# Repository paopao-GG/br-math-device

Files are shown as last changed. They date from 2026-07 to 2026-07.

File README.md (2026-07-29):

# BR Math Device

Arduino Mega firmware for a 3-level multiple-choice quiz prop. Questions are on
paper; the device judges the answers. See [TDD.md](TDD.md) for the full design.

## How it plays

Three levels hold nine questions between them. One LED and one button belong to each
**level**, not to each question:

| Level | Questions | Code digits it locks | Button | LED |
|---|---|---|---|---|
| 1 | 5 | 1, 2, 3 | 23 | 22 |
| 2 | 3 | 4 | 25 | 24 |
| 3 | 1 | 5 | 27 | 26 |

**Pick a set first.** There are three sets of paper questions, each with its own four
RFID cards (twelve in all). At boot the LCD shows `SCAN TO PICK SET`; the player scans
any card from the set they want, then presses **button 1** to confirm:

```
SCAN TO PICK SET          SET 2 SELECTED
ANY A/B/C/D CARD   -->     PRESS 1 TO START   -->  game begins on set 2
```

Scanning a different set's card changes the choice; an unrecognised card is ignored.
To change sets after starting, power-cycle.

Once a set is confirmed the device picks a random 5-digit code (digits 1–9, different
every boot) and shows it on the LCD. Each level then runs in two phases:

**Quiz phase** — scan one of the selected set's four RFID cards (A/B/C/D) as the
answer, press the level's button.

```
CODE:47391 L1Q3     <- the code, then level 1 question 3
ANS:C   [##...]     <- the scanned card, then this level's 5 questions
```

- correct → the LED **blinks twice** and the next question opens
- wrong, or no card scanned → **no blink**, miss tune, and the *same question stays
  live*. There is no way past a question except by answering it.

**Code phase** — once every question in the level is cleared, dial the level's share
of the code on the potentiometer and press the same button to lock each digit.

```
CODE:47391 L1D2     <- level 1, code digit 2 of the 3 it owns
DIAL:7  [47_..]     <- the live pot digit, then all five code slots
```

- correct digit → LED blinks once, digit latches, next slot opens
- wrong digit → no blink, miss tune, retry the same slot
- the level's **last** digit → LED goes **solid** and the next level begins

After level 3's digit locks, all three LEDs are solid and the LCD shows `SOLVED!`
with the code and a `MISSES:n` count. Because a question can only be retried, every
game ends solved — the miss count is what says how cleanly. Power-cycle for a new code.

Each set has its own fixed answer key (`ANSWER_KEYS` in [config.h](config.h)), laid out
`L1 (5) | L2 (3) | L3 (1)`:

| Set | L1 Q1–5 | L2 Q1–3 | L3 |
|---|---|---|---|
| **1** | B D A C D | A C B | D |
| **2** | C A D B A | D B C | A |
| **3** | D B C A B | C A D | B |

Only the selected set's cards score; a card from another set reads as `?` and counts
wrong.

## Wiring (Arduino Mega 2560)

Summary below. **[WIRING.md](WIRING.md) has the wire-by-wire tables** — use that one at
the bench.

| Part | Pins |
|---|---|
| RC522 RFID | SS→53, SCK→52, MOSI→51, MISO→50, RST→49, **VCC→3.3V**, GND→GND |
| 1602 I2C LCD | SDA→20, SCL→21, VCC→5V, GND→GND |
| Potentiometer ×1 | wiper → A0; outer legs → 5V and GND |
| LEDs ×3 | 22, 24, 26 → 220Ω resistor → LED → GND |
| Buttons ×3 | 23, 25, 27 → button → GND (no resistors; internal pullups) |
| Passive buzzer | 8 → buzzer → GND |
| A15 | **leave unconnected** |

Two things bite people here:

- **The RC522 runs on 3.3V.** Putting it on 5V destroys it. Its logic pins are fine
  on the Mega's 5V SPI lines; it's only VCC that matters.
- **A15 must stay floating.** Its electrical noise is what seeds the random code.
  Wire anything to it and every boot produces the same code.

LED 1 goes with button 1 and level 1, and so on. The single potentiometer is shared by
every level.

LEDs on 28/30 and buttons on 29/31 are left over from the earlier five-round build. They
stay wired and are never read or driven — the firmware doesn't even configure those pins.

## Libraries

Two are needed, both via the Arduino IDE's **Library Manager**:

- **MFRC522** (by GithubCommunity) — for the RFID reader. Not yet installed.
- **LiquidCrystal I2C** — already installed here (Frank de Brabander's version).

Several different libraries are all called "LiquidCrystal_I2C" and they disagree on
how to start the display — de Brabander's uses `begin()`, the others use `init()`.
The sketch detects which one you have at compile time and calls the right one, so any
of them will work. You don't need to do anything about this; it's noted only because
the resulting error message (`no member named 'begin'`) is otherwise baffling.

## Bring-up

**1. The card UIDs are already filled in.** All twelve (three sets × A/B/C/D) are in
`CARD_UIDS` in [config.h](config.h), transcribed from `rfid-uid.txt`. You only need the
next two steps if you **replace a card** or add a new one.

**2. (Only if replacing a card) Read its UID.** Open `tools/uid_dump/uid_dump.ino` in
the Arduino IDE, upload it, open the Serial Monitor at 9600 baud, and tap the card. It
prints a paste-ready line:

```
Card detected!
  UID (hex):  DE AD BE EF
  Paste this: {0xDE, 0xAD, 0xBE, 0xEF},
```

Paste it into the right `CARD_UIDS[set][letter]` slot. The order matters on both axes —
outer index is the set (0=set 1…), inner is A, B, C, D — because `ANSWER_KEYS` indexes
into it, so a wrong slot scores that set against the wrong card. If a card prints nothing
at all, the reader is miswired or on 5V.

**3. Flash the game.** Open `br-math-device.ino` in the Arduino IDE and upload.

(If you prefer the command line, PlatformIO works too: `pio run -t upload` for the
game, `pio run -d tools/uid_dump -t upload` for the UID reader.)

## Checks

- Blank or garbled LCD: run an I2C scanner and change `LCD_ADDR` in config.h to `0x3F`.
- Scan beep too quiet to hear across the room: raise the duration in `TUNE_SCAN`
  (config.h). It beeps on every recognised card read.
- Set selection sanity check: at boot, scan one card from each set — each should report
  its own set (`SET 1/2/3`). If two different cards report the same set, or the wrong
  one, the `CARD_UIDS` blocks in config.h are ordered wrong.
- Digit flickering between two values as the pot rests: raise `POT_HYSTERESIS`. Pot
  feeling sticky or refusing to reach 1 or 9: lower it.
- Turning the pot must only ever change the digit in the `_` slot. If it also moves a
  digit you already locked in, the latch is broken.
- The pot is deliberately dead during a quiz phase — `DIAL:` only appears once all of a
  level's questions are answered. That's not a fault.
- The one test worth doing deliberately: answer a question with the **wrong card**. The
  LED must not blink and the LCD must still show the same `LxQy`. That proves the
  retry rule is live — a question can't be skipped, only answered.
- The Serial Monitor narrates the whole game — the code, each question's expected card,
  each slot's expected digit, what was scanned or dialed, and every miss.

## Layout

- `br-math-device.ino` — the game
- `config.h` — pins, per-set answer keys, card UIDs, tunes, tuning constants. Everything
  you'd want to change is in here.
- `WIRING.md` — wire-by-wire connection tables
- `TDD.md` — the design doc: hardware, game flow, rules
- `tools/uid_dump/` — the card UID reader
- `platformio.ini` — for building from the CLI; the Arduino IDE works without it

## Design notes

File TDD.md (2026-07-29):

# TDD — Math Device

Technical design for a 3-level multiple-choice quiz device built on an Arduino Mega.
The questions are printed on paper; the device's job is to take the player's answer
physically — as an RFID card, and later as a dialed digit — and judge it.

## Hardware Components

| Qty | Component |
|-----|---|
| 1 | Arduino Mega |
| 1 | RFID reader (RC522) |
| 12 | RFID card — 3 sets of 4, each marked A, B, C, D |
| 3 | Push button |
| 3 | LED |
| 1 | Potentiometer |
| 1 | 1602 I2C LCD |
| 1 | Passive buzzer |

One LED and one push button belong to each of the 3 **levels** — not to each question.
The **single potentiometer is shared by every level**; it is used only when a level
reaches its code phase.

## Question sets

There are **three separate sets of paper questions**, each with its own four RFID cards
(twelve cards in all) and its own answer key. At boot the player picks one set; the rest
of the game runs against that set alone. Within the chosen set the four cards are the
A/B/C/D answers, reused for every question exactly as before — the set dimension sits
entirely in front of the game.

An earlier revision of this device used 5 LEDs and 5 buttons. Those extra parts stay
wired on the board and are simply unused — see WIRING.md.

## Game Shape

Three levels hold nine questions between them. A level is not one question: it is a run
of questions followed by the share of the code that level unlocks.

| Level | Questions | Code digits it locks | Button | LED |
|---|---|---|---|---|
| 1 | 5 | 1, 2, 3 | 23 | 22 |
| 2 | 3 | 4 | 25 | 24 |
| 3 | 1 | 5 | 27 | 26 |

The code is still **5 digits** — it is just no longer one digit per question.

## System / Game Flow

### 1. Power on — pick a set

Before the game starts the LCD asks for a set:

```
SCAN TO PICK SET
ANY A/B/C/D CARD
```

The player scans **any card from the set they want**. The device recognises which set
the card belongs to and shows it:

```
SET 2 SELECTED
PRESS 1 TO START
```

Scanning a card from a different set changes the choice; scanning a card that is none of
the twelve plays the miss tone and is ignored. Pressing **button 1** confirms the
highlighted set and begins the game. (Pressed before any card is scanned, it does
nothing.) To change sets after starting, power-cycle.

### 2. Start of game

Once a set is confirmed the system generates a **5-digit code** — digits 1–9 only, a new
code every restart — shows a brief `SET n - START / GET READY...` screen, then displays
the code. Line 1 is constant through the game; line 2 changes with the phase:

```
Quiz phase          Code phase
CODE:47391 L1Q3     CODE:47391 L1D2
ANS:C   [##...]     DIAL:7  [47_..]
```

- **Line 1** — the code, then the position: `L1Q3` is level 1, question 3; `L1D2` is
  level 1, code digit 2 of the 3 that level owns.
- **Line 2, quiz phase** — `ANS:` is the card currently scanned (`-` if none, `?` if the
  card is not one of the selected set's four). The bar has one cell per question *in this
  level* — 5, 3 or 1 wide — with `#` for answered and `.` for still to come.
- **Line 2, code phase** — `DIAL:` is the live potentiometer digit. The bar shows all
  five code slots: digits locked so far, `_` for the slot being dialed, `.` for slots
  no level has reached yet.

The pot is **not** shown during the quiz phase, because it does nothing there.

### 3. Quiz phase

Each question is one multiple-choice question on paper, with choices A, B, C, D. The
player:

1. Picks the RFID card marked with their answer and **scans it**. The buzzer beeps to
   confirm the read. Rescanning replaces the answer — the last scan counts.
2. Presses **the current level's button** to submit.

On the press:

- **Correct** — the level's LED **blinks twice**, and the next question opens.
- **Wrong, or no card scanned** — the LED does **not** blink, the buzzer plays the miss
  tune, and the *same question stays live*. The pending card is cleared, so the player
  must scan again rather than press repeatedly.

**There is no way past a question except by answering it correctly.** The device counts
misses but never blocks or ends the game.

### 4. Code phase

Once every question in the level is answered, the level switches to code entry. For
each digit slot the level owns, the player:

1. Turns **the potentiometer** to that digit of the code shown on the LCD.
2. Presses **the same button** to lock it.

- **Correct digit** — the LED blinks once, the digit latches, and the next slot opens.
- **Wrong digit** — no blink, miss tune, the slot stays live to be retried.
- **The level's last digit** — the LED turns **SOLID** and stays solid for the rest of
  the game, and the next level begins.

The button press latches the dialed digit, which is what allows a single potentiometer
to serve every slot: once latched, the digit is frozen, and turning the pot afterwards
cannot disturb it — it now drives the next slot instead.

### 5. End of game

After level 3's digit locks, all three LEDs are solid and the LCD shows:

```
SOLVED!  47391
MISSES:3
```

The buzzer plays the win tune. Because a question can only be retried, every game ends
solved — so what the device reports is how cleanly it was done, not whether it was done.
Power-cycle to play again with a new code.

## Rules

**Answer keys.** One card per question, and a separate key per set (the paper questions
differ between sets). Laid out level by level:

| Set | L1 Q1 | Q2 | Q3 | Q4 | Q5 | L2 Q1 | Q2 | Q3 | L3 Q1 |
|---|---|---|---|---|---|---|---|---|---|
| **1** | B | D | A | C | D | A | C | B | D |
| **2** | C | A | D | B | A | D | B | C | A |
| **3** | D | B | C | A | B | C | A | D | B |

Each key uses all four cards in its level-1 span, and no card repeats back-to-back
anywhere (including across level boundaries). Level 1 has five questions but only four
cards, so one card repeats per row, kept far apart so it does not read as a pattern.

These are fixed and do not change between restarts — only the 5-digit code is random.
They live in `ANSWER_KEYS` in [config.h](config.h) and are edited to match the paper.

**Cards.** Twelve, in three sets of four (A/B/C/D). Only the selected set's four cards
score; a card from another set reads as `?` and counts as wrong. The set is chosen once
at boot (see step 1) and cannot change without a power-cycle.

**Buttons.** Only the current level's button is live. The other two are ignored, so a
stray press cannot skip ahead. Buttons 4 and 5 from the old build are never read at all.
During set selection, button 1 is the confirm button.

**Potentiometer.** One pot, shared. It is idle during a quiz phase, and during a code
phase it drives the slot being dialed. The digit it is showing when the button is
pressed is the one that counts.

**Buzzer.** Beeps on every RFID scan, plays the level's tune on a correct answer, a miss
tune on any wrong answer or wrong digit, a lock tune per code digit, a clear tune when a
level's LED goes solid, and the win tune at the end.

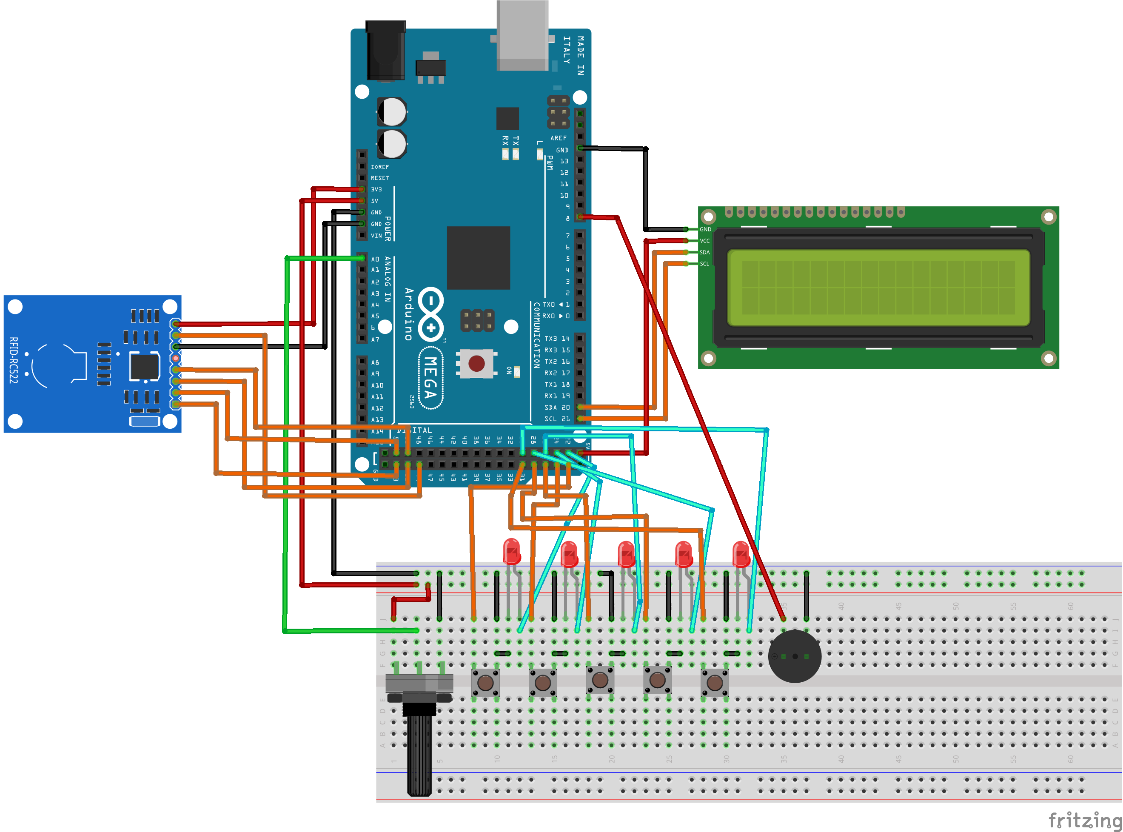
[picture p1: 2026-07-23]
circuit_bb.png

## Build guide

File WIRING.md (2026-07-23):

# Wiring — BR Math Device (Arduino Mega 2560)

## Power

| Rail | Feeds |
|---|---|
| **3.3V** | RC522 RFID reader **only** |
| **5V** | LCD, potentiometer, buttons (via internal pullups), buzzer |
| **GND** | Everything — all grounds must be common |

The Mega has several GND pins; any of them will do, and you'll need a breadboard ground
rail since almost every component needs one.

## RC522 RFID reader

| RC522 pin | Mega pin |
|---|---|
| SDA / SS | **53** |
| SCK | **52** |
| MOSI | **51** |
| MISO | **50** |
| IRQ | *not connected* |
| GND | GND |
| RST | **49** |
| VCC | **3.3V** — see warning below |

SCK, MOSI and MISO are the Mega's hardware SPI pins and cannot be moved. SS and RST can
be changed in config.h if you need those pins for something else.

## 1602 I2C LCD

| LCD pin | Mega pin |
|---|---|
| GND | GND |
| VCC | 5V |
| SDA | **20** |
| SCL | **21** |

I2C address is `0x27` (`LCD_ADDR` in config.h). Some backpacks ship as `0x3F` — if the
screen stays blank or shows only blocks, run an I2C scanner and change it.

## Potentiometer ×1

There is a **single** potentiometer, shared by all three levels — it drives whichever
code slot is being dialed. Three wires:

| Pot leg | Mega pin |
|---|---|
| Outer leg 1 | 5V |
| Wiper (middle) | **A0** |
| Outer leg 2 | GND |

If it reads backwards (turning right lowers the digit), swap the two outer legs.

## LEDs ×3

Each LED: Mega pin → 220Ω resistor → LED **anode** (long leg); LED **cathode** (short
leg, flat side of the rim) → GND.

| LED | Mega pin | |
|---|---|---|
| LED 1 | **22** | level 1 |
| LED 2 | **24** | level 2 |
| LED 3 | **26** | level 3 |
| ~~LED 4~~ | ~~28~~ | unused |
| ~~LED 5~~ | ~~30~~ | unused |

## Buttons ×3

Each button: one leg → Mega pin, other leg → GND. **No resistors** — the firmware uses
the Mega's internal pullups, so a pressed button reads LOW.

| Button | Mega pin | |
|---|---|---|
| Button 1 | **23** | level 1 |
| Button 2 | **25** | level 2 |
| Button 3 | **27** | level 3 |
| ~~Button 4~~ | ~~29~~ | unused |
| ~~Button 5~~ | ~~31~~ | unused |

On a 4-leg tactile switch, the legs are paired internally. Use two legs that are
diagonally opposite each other and you can't get it wrong.

**About LEDs/buttons 4 and 5.** They are left over from the earlier five-round build. If
they are already soldered, leave them — the firmware never configures pins 28–31, so those
LEDs simply stay dark and those buttons do nothing. Nothing needs unwiring. On a fresh
build, don't fit them.

## Passive buzzer

| Buzzer pin | Mega pin |
|---|---|
| + (signal) | **8** |
| − | GND |

Must be a **passive** buzzer. An active buzzer only makes one fixed tone and the
per-button tunes won't work.

## Level mapping

Level N uses LED N and button N — one set per **level**, not per question. The single
potentiometer is shared by all three levels, so it has no column here. Wire each LED with
its button as a set — swapping two levels fails silently, because the device still runs
and just blinks the wrong LED.

| Level | Questions | Code digits | LED | Button |
|---|---|---|---|---|
| 1 | 5 | 1, 2, 3 | 22 | 23 |
| 2 | 3 | 4 | 24 | 25 |
| 3 | 1 | 5 | 26 | 27 |

## Full pin usage

| Mega pin | Used by |
|---|---|
| 8 | Buzzer |
| 20 (SDA) | LCD |
| 21 (SCL) | LCD |
| 22 | LED 1 |
| 23 | Button 1 |
| 24 | LED 2 |
| 25 | Button 2 |
| 26 | LED 3 |
| 27 | Button 3 |
| 28–31 | *LEDs/buttons 4–5 — wired but unused* |
| 49 | RC522 RST |
| 50 (MISO) | RC522 |
| 51 (MOSI) | RC522 |
| 52 (SCK) | RC522 |
| 53 (SS) | RC522 |
| A0 | Potentiometer wiper |
| A1–A4 | *free* |
| A15 | **Reserved — leave unconnected** |
| 3.3V | RC522 VCC |
| 5V | LCD, potentiometer |

Everything else on the board is free.

## Three things that will bite you

**The RC522 runs on 3.3V.** Putting its VCC on 5V destroys the module — this is the one
mistake here that costs you a part rather than an afternoon. Its data pins are fine
connected directly to the Mega's 5V SPI pins; it's only VCC that matters.

**A15 must stay unconnected.** The firmware reads the electrical noise on that floating
pin to seed the random number generator. Wire anything to it and the pin stops floating,
so every power-up generates the *same* 5-digit code.

**LEDs are polarised and need their resistor.** Long leg (anode) toward the 220Ω resistor
and the Mega pin, short leg (cathode) to GND. Backwards, it simply won't light; without
the resistor, you'll eventually kill the LED or the pin driving it.

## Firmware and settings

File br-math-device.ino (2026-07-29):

/*
 * BR Math Device
 *
 * A 3-level multiple-choice quiz prop. The questions themselves are on paper;
 * the device only judges the answers.
 *
 * There are three separate SETS of paper questions, each with its own four RFID
 * cards (twelve cards in all) and its own answer key. At boot the player picks a
 * set by scanning any card from it and pressing button 1 to confirm; the rest of
 * the game then runs against that set alone.
 *
 * Three levels hold nine questions between them - five, then three, then one.
 * Each level runs in two phases:
 *
 *   QUIZ  the level's questions, one at a time. Scan one of four RFID cards
 *         (A/B/C/D) as the answer and press the level's button. Correct, the LED
 *         blinks twice and the next question opens. Wrong, it does not blink at
 *         all and the SAME question stays live - there is no way past a question
 *         except by answering it.
 *
 *   CODE  once every question is cleared, the level unlocks its share of the
 *         5-digit code: three digits for level 1, one each for levels 2 and 3.
 *         Dial each digit on the potentiometer and press the same button to lock
 *         it. The level's last digit turns its LED SOLID and opens the next level.
 *
 * On power-up the device picks a random 5-digit code (digits 1-9) and shows it on
 * the LCD. Because a wrong answer can only be retried, every game ends solved;
 * what the device records instead is the number of misses along the way.
 *
 * There is ONE potentiometer. It does nothing during a QUIZ phase and drives the
 * digit being dialed during a CODE phase; pressing the button latches that digit,
 * freeing the pot for the next slot.
 *
 * LEDs and buttons 4 and 5 are left over from the earlier five-round build. They
 * stay wired and are deliberately unused.
 *
 * Before this sketch is useful, the four card UIDs must be filled into
 * CARD_UIDS in config.h. See tools/uid_dump/uid_dump.ino.
 *
 * Wiring is documented in config.h. The one thing worth repeating: the RC522
 * runs on 3.3V, not 5V.
 */

#include <SPI.h>
#include <MFRC522.h>
#include <Wire.h>
#include <LiquidCrystal_I2C.h>

#include "config.h"

// ---------------------------------------------------------------------------
// State
// ---------------------------------------------------------------------------

enum GameState : uint8_t {
  STATE_SELECT,    // choosing which question set to play, before the game proper
  STATE_PLAYING,
  STATE_DONE
};

// Which half of the current level we are in. A button press means "judge my
// card" in one and "lock this digit" in the other, so almost everything below
// dispatches on this.
enum Phase : uint8_t {
  PHASE_QUIZ,
  PHASE_CODE
};

MFRC522 mfrc522(RFID_SS_PIN, RFID_RST_PIN);
LiquidCrystal_I2C lcd(LCD_ADDR, LCD_COLS, LCD_ROWS);

GameState state = STATE_SELECT;
Phase     phase = PHASE_QUIZ;

uint8_t selectedSet = 0;       // which question set is being played, 0..NUM_SETS-1
int8_t  pendingSet  = -1;      // set highlighted during selection, -1 = none yet

uint8_t currentLevel    = 0;   // 0..NUM_LEVELS-1
uint8_t currentQuestion = 0;   // index within the current level
uint8_t currentSlot     = 0;   // code-digit index within the current level

uint8_t codeDigit[CODE_LENGTH];     // the secret code, 1-9 per slot
uint8_t lockedDigit[CODE_LENGTH];   // digits the player has locked in, for display
uint8_t potDigit;                   // the pot's live reading, 1-9. Meaningful only
                                    // during a CODE phase.

uint16_t misses = 0;                // wrong cards + wrong digits + empty presses

CardId scannedCard = CARD_NONE;     // pending answer for the current question

// Button debounce, one slot per level's button.
bool          buttonStable[NUM_LEVELS];      // true = pressed
bool          buttonLastRead[NUM_LEVELS];
unsigned long buttonLastChangeMs[NUM_LEVELS];

// Last strings pushed to the LCD, so we only redraw on change.
char prevLine1[LCD_COLS + 1] = "";
char prevLine2[LCD_COLS + 1] = "";

// ---------------------------------------------------------------------------
// Level geometry
// ---------------------------------------------------------------------------

// LEVEL_QUESTIONS and LEVEL_CODE_DIGITS in config.h are the only source of truth
// for the shape of the game. Everything else is summed from them here rather than
// written down a second time, so the two can never drift apart.

uint8_t questionBase(uint8_t level) {
  uint8_t base = 0;
  for (uint8_t i = 0; i < level; i++) base += LEVEL_QUESTIONS[i];
  return base;
}

uint8_t digitBase(uint8_t level) {
  uint8_t base = 0;
  for (uint8_t i = 0; i < level; i++) base += LEVEL_CODE_DIGITS[i];
  return base;
}

// Index into a set's ANSWER_KEYS row for the question on screen right now.
uint8_t currentQuestionIndex() {
  return questionBase(currentLevel) + currentQuestion;
}

// Index into codeDigit[] for the slot being dialed right now. Also the count of
// slots already locked, which is what the LCD needs to draw the code bar.
uint8_t currentSlotIndex() {
  return digitBase(currentLevel) + currentSlot;
}

// ---------------------------------------------------------------------------
// Buzzer
// ---------------------------------------------------------------------------

// Blocking, which is fine: the game is turn-based and nothing needs servicing
// while a tune plays.
void playTune(const Note* tune, uint8_t length) {
  for (uint8_t i = 0; i < length; i++) {
    tone(BUZZER_PIN, tune[i].freq, tune[i].duration);
    delay(tune[i].duration + 25);
  }
  noTone(BUZZER_PIN);
}

// ---------------------------------------------------------------------------
// LEDs
// ---------------------------------------------------------------------------

// Blocking for the same reason playTune() is. Only ever called on the current
// level, whose LED is off - the cleared levels behind it are solid and stay solid.
void blinkLed(uint8_t level, uint8_t times) {
  for (uint8_t i = 0; i < times; i++) {
    digitalWrite(LED_PINS[level], HIGH);
    delay(BLINK_ON_MS);
    digitalWrite(LED_PINS[level], LOW);
    delay(BLINK_OFF_MS);
  }
}

// ---------------------------------------------------------------------------
// Potentiometer (one, shared by all levels)
// ---------------------------------------------------------------------------

const uint8_t POT_BANDS = POT_MAX_DIGIT - POT_MIN_DIGIT + 1;

// The ADC range is split into POT_BANDS equal slices, one per digit.
int bandLow(uint8_t digit) {
  return ((long)(digit - POT_MIN_DIGIT) * 1024L) / POT_BANDS;
}

int bandHigh(uint8_t digit) {
  return (((long)(digit - POT_MIN_DIGIT + 1) * 1024L) / POT_BANDS) - 1;
}

uint8_t rawToDigit(int raw) {
  int digit = ((long)raw * POT_BANDS) / 1024L + POT_MIN_DIGIT;
  return constrain(digit, POT_MIN_DIGIT, POT_MAX_DIGIT);
}

int readPotRaw() {
  long sum = 0;
  for (uint8_t i = 0; i < POT_SAMPLES; i++) {
    sum += analogRead(POT_PIN);
  }
  return sum / POT_SAMPLES;
}

// Only move off the current digit once the pot has travelled POT_HYSTERESIS
// counts PAST the edge of that digit's band. A pot resting exactly on a band
// edge would otherwise flicker between two digits on ADC noise alone, which
// makes the code impossible to dial reliably.
void updatePotDigit() {
  int raw = readPotRaw();

  if (raw < bandLow(potDigit) - POT_HYSTERESIS ||
      raw > bandHigh(potDigit) + POT_HYSTERESIS) {
    potDigit = rawToDigit(raw);
  }
}

// ---------------------------------------------------------------------------
// Buttons
// ---------------------------------------------------------------------------

// Returns true once per press, on the debounced falling edge.
bool buttonPressed(uint8_t level) {
  bool reading = (digitalRead(BUTTON_PINS[level]) == LOW);  // INPUT_PULLUP

  if (reading != buttonLastRead[level]) {
    buttonLastRead[level] = reading;
    buttonLastChangeMs[level] = millis();
    return false;
  }

  if (millis() - buttonLastChangeMs[level] < BUTTON_DEBOUNCE_MS) {
    return false;
  }

  if (reading != buttonStable[level]) {
    buttonStable[level] = reading;
    return reading;  // fire on press, not release
  }

  return false;
}

// Sync the debouncer to whatever this button is doing right now, so a button
// already held down when the level opens does not read as a fresh press.
void syncButton(uint8_t level) {
  bool held = (digitalRead(BUTTON_PINS[level]) == LOW);
  buttonStable[level] = held;
  buttonLastRead[level] = held;
  buttonLastChangeMs[level] = millis();
}

// ---------------------------------------------------------------------------
// RFID
// ---------------------------------------------------------------------------

// Reads a card if one is on the reader. Returns false when nothing was there this
// pass, so a pending answer is left alone. Returns true whenever a card was read -
// even a card that is none of ours - so the caller can still beep and show '?'.
// A wrong-size UID leaves out[] zeroed, which matches no real card.
bool readUid(byte out[UID_LENGTH]) {
  if (!mfrc522.PICC_IsNewCardPresent()) return false;
  if (!mfrc522.PICC_ReadCardSerial())   return false;

  memset(out, 0, UID_LENGTH);
  if (mfrc522.uid.size == UID_LENGTH) {
    memcpy(out, mfrc522.uid.uidByte, UID_LENGTH);
  }

  // Required, or the same card cannot be scanned a second time.
  mfrc522.PICC_HaltA();
  mfrc522.PCD_StopCrypto1();

  return true;
}

// Which of the given set's four cards this UID is, or CARD_UNKNOWN. During play a
// card from any OTHER set falls through to CARD_UNKNOWN and reads as '?'.
CardId matchInSet(const byte uid[UID_LENGTH], uint8_t set) {
  for (uint8_t c = 0; c < NUM_CARDS; c++) {
    if (memcmp(uid, CARD_UIDS[set][c], UID_LENGTH) == 0) return (CardId)c;
  }
  return CARD_UNKNOWN;
}

// Which set this UID belongs to, or -1 if it is none of the twelve. Used only
// during selection. UIDs are unique across sets, so the first match is the answer.
int8_t matchSet(const byte uid[UID_LENGTH]) {
  for (uint8_t s = 0; s < NUM_SETS; s++) {
    if (matchInSet(uid, s) != CARD_UNKNOWN) return s;
  }
  return -1;
}

bool uidsConfigured() {
  for (uint8_t s = 0; s < NUM_SETS; s++) {
    for (uint8_t c = 0; c < NUM_CARDS; c++) {
      for (uint8_t b = 0; b < UID_LENGTH; b++) {
        if (CARD_UIDS[s][c][b] != 0x00) return true;
      }
    }
  }
  return false;
}

// ---------------------------------------------------------------------------
// Display
// ---------------------------------------------------------------------------

char cardLetter(CardId card) {
  switch (card) {
    case CARD_A: return 'A';
    case CARD_B: return 'B';
    case CARD_C: return 'C';
    case CARD_D: return 'D';
    case CARD_UNKNOWN: return '?';   // card read, but not one of ours
    default: return '-';             // nothing scanned yet
  }
}

// The LCD is on I2C and slow. Redrawing every loop makes it visibly flicker,
// so only push a line when its content actually changed.
void writeLine(uint8_t row, const char* text, char* previous) {
  if (strcmp(text, previous) == 0) return;

  lcd.setCursor(0, row);

  uint8_t i = 0;
  for (; i < LCD_COLS && text[i] != '\0'; i++) {
    lcd.print(text[i]);
  }
  for (; i < LCD_COLS; i++) {
    lcd.print(' ');   // blank out whatever the previous line left behind
  }

  strncpy(previous, text, LCD_COLS);
  previous[LCD_COLS] = '\0';
}

// Line 1 is the same in both phases apart from its Q/D marker: the code, then
// where we are. e.g. "CODE:47391 L1Q3" or "CODE:47391 L1D2".
void formatHeader(char* out, size_t size, char marker, uint8_t index) {
  snprintf(out, size, "CODE:%u%u%u%u%u L%u%c%u",
           codeDigit[0], codeDigit[1], codeDigit[2], codeDigit[3], codeDigit[4],
           currentLevel + 1, marker, index + 1);
}

// e.g. "ANS:C   [##...]" - the pending card, then one cell per question in this
// level: '#' answered, '.' still to come. The bar is 5, 3 or 1 wide by level.
void renderQuiz() {
  char line1[LCD_COLS + 1];
  char line2[LCD_COLS + 1];

  formatHeader(line1, sizeof(line1), 'Q', currentQuestion);

  char* cursor = line2;
  cursor += sprintf(cursor, "ANS:%c   [", cardLetter(scannedCard));
  for (uint8_t q = 0; q < LEVEL_QUESTIONS[currentLevel]; q++) {
    *cursor++ = (q < currentQuestion) ? '#' : '.';
  }
  *cursor++ = ']';
  *cursor = '\0';

  writeLine(0, line1, prevLine1);
  writeLine(1, line2, prevLine2);
}

// e.g. "DIAL:7  [47_..]" - the live pot digit, then all five code slots: the
// digits locked so far, '_' for the slot being dialed, '.' for slots no level
// has reached yet.
void renderCode() {
  char line1[LCD_COLS + 1];
  char line2[LCD_COLS + 1];

  formatHeader(line1, sizeof(line1), 'D', currentSlot);

  uint8_t lockedCount = currentSlotIndex();

  char* cursor = line2;
  cursor += sprintf(cursor, "DIAL:%u  [", potDigit);
  for (uint8_t s = 0; s < CODE_LENGTH; s++) {
    if (s < lockedCount)       *cursor++ = '0' + lockedDigit[s];
    else if (s == lockedCount) *cursor++ = '_';
    else                       *cursor++ = '.';
  }
  *cursor++ = ']';
  *cursor = '\0';

  writeLine(0, line1, prevLine1);
  writeLine(1, line2, prevLine2);
}

// Every game ends solved - a question cannot be skipped - so the score to report
// is how cleanly it was done, not whether it was done.
void renderResult() {
  char line1[LCD_COLS + 1];
  char line2[LCD_COLS + 1];

  snprintf(line1, sizeof(line1), "SOLVED!  %u%u%u%u%u",
           codeDigit[0], codeDigit[1], codeDigit[2], codeDigit[3], codeDigit[4]);
  snprintf(line2, sizeof(line2), "MISSES:%u", misses);

  writeLine(0, line1, prevLine1);
  writeLine(1, line2, prevLine2);

  playTune(TUNE_WIN, TUNE_WIN_LENGTH);

  Serial.print(F("Solved with "));
  Serial.print(misses);
  Serial.println(F(" miss(es)."));
}

// ---------------------------------------------------------------------------
// Game flow
// ---------------------------------------------------------------------------

void startQuestion() {
  scannedCard = CARD_NONE;

  Serial.print(F("  L"));
  Serial.print(currentLevel + 1);
  Serial.print(F(" Q"));
  Serial.print(currentQuestion + 1);
  Serial.print('/');
  Serial.print(LEVEL_QUESTIONS[currentLevel]);
  Serial.print(F(" expects card "));
  Serial.println(cardLetter(ANSWER_KEYS[selectedSet][currentQuestionIndex()]));
}

void enterCodePhase() {
  phase = PHASE_CODE;
  scannedCard = CARD_NONE;

  // The pot has been ignored for the whole quiz phase and may have been turned
  // in that time, so resync before showing it - otherwise the first digit on the
  // LCD is a stale reading that does not match where the knob is pointing.
  potDigit = rawToDigit(readPotRaw());

  Serial.print(F("  L"));
  Serial.print(currentLevel + 1);
  Serial.print(F(" questions cleared - dial "));
  Serial.print(LEVEL_CODE_DIGITS[currentLevel]);
  Serial.println(F(" code digit(s)"));
  Serial.print(F("  slot 1 expects digit "));
  Serial.println(codeDigit[currentSlotIndex()]);
}

void startLevel(uint8_t level) {
  currentLevel = level;
  currentQuestion = 0;
  currentSlot = 0;
  phase = PHASE_QUIZ;

  syncButton(level);

  Serial.print(F("Level "));
  Serial.print(level + 1);
  Serial.print(F(" - "));
  Serial.print(LEVEL_QUESTIONS[level]);
  Serial.print(F(" question(s), then "));
  Serial.print(LEVEL_CODE_DIGITS[level]);
  Serial.println(F(" code digit(s)"));

  startQuestion();
}

void finishGame() {
  state = STATE_DONE;
  renderResult();
}

// QUIZ phase: judge the scanned card. A wrong answer costs a miss and leaves the
// question exactly where it was - the only way forward is to get it right.
void submitAnswer() {
  bool correct = (scannedCard == ANSWER_KEYS[selectedSet][currentQuestionIndex()]);

  Serial.print(F("    answered "));
  Serial.print(cardLetter(scannedCard));
  Serial.println(correct ? F(" (correct)") : F(" (wrong - retry)"));

  if (!correct) {
    misses++;
    playTune(TUNE_WRONG, TUNE_WRONG_LENGTH);
    scannedCard = CARD_NONE;   // force a fresh scan rather than button-mashing
    return;
  }

  blinkLed(currentLevel, CORRECT_BLINKS);
  playTune(BUTTON_TUNES[currentLevel], BUTTON_TUNE_LENGTHS[currentLevel]);

  currentQuestion++;
  if (currentQuestion < LEVEL_QUESTIONS[currentLevel]) {
    startQuestion();
  } else {
    enterCodePhase();
  }
}

// CODE phase: judge the dialed digit, and on success latch it. Latching is what
// lets one pot serve every slot - the digit is frozen here, so the pot is free to
// move on without disturbing what is already locked.
void submitDigit() {
  uint8_t slot = currentSlotIndex();
  uint8_t dialed = potDigit;

  Serial.print(F("    dialed "));
  Serial.print(dialed);

  if (dialed != codeDigit[slot]) {
    Serial.print(F(" (wrong - expected "));
    Serial.print(codeDigit[slot]);
    Serial.println(F(", retry)"));
    misses++;
    playTune(TUNE_WRONG, TUNE_WRONG_LENGTH);
    return;
  }

  Serial.println(F(" (locked)"));
  lockedDigit[slot] = dialed;
  currentSlot++;

  if (currentSlot < LEVEL_CODE_DIGITS[currentLevel]) {
    blinkLed(currentLevel, DIGIT_BLINKS);
    playTune(TUNE_DIGIT_LOCK, TUNE_DIGIT_LOCK_LENGTH);
    Serial.print(F("  slot "));
    Serial.print(currentSlot + 1);
    Serial.print(F(" expects digit "));
    Serial.println(codeDigit[currentSlotIndex()]);
    return;
  }

  // Last digit of the level: the LED goes solid and stays solid for the rest of
  // the game, so the lit LEDs read as a progress bar across the three levels.
  digitalWrite(LED_PINS[currentLevel], HIGH);
  playTune(TUNE_LEVEL_CLEAR, TUNE_LEVEL_CLEAR_LENGTH);

  Serial.print(F("Level "));
  Serial.print(currentLevel + 1);
  Serial.println(F(" CLEARED"));

  if (currentLevel + 1 < NUM_LEVELS) {
    startLevel(currentLevel + 1);
  } else {
    finishGame();
  }
}

void newGame() {
  randomSeed(analogRead(RANDOM_SEED_PIN));

  for (uint8_t i = 0; i < CODE_LENGTH; i++) {
    codeDigit[i] = random(1, 10);   // 1-9, never 0
    lockedDigit[i] = 0;
  }
  for (uint8_t i = 0; i < NUM_LEVELS; i++) {
    digitalWrite(LED_PINS[i], LOW);
  }

  misses = 0;
  potDigit = rawToDigit(readPotRaw());   // start from wherever the pot actually is

  Serial.print(F("Code: "));
  for (uint8_t i = 0; i < CODE_LENGTH; i++) Serial.print(codeDigit[i]);
  Serial.println();

  lcd.clear();
  prevLine1[0] = '\0';
  prevLine2[0] = '\0';

  lcd.setCursor(0, 0);
  lcd.print(F("SET "));
  lcd.print(selectedSet + 1);
  lcd.print(F(" - START"));
  lcd.setCursor(0, 1);
  lcd.print(F("GET READY..."));
  delay(1500);
  lcd.clear();

  state = STATE_PLAYING;
  startLevel(0);
}

// ---------------------------------------------------------------------------
// Set selection (runs once at boot, before the game proper)
// ---------------------------------------------------------------------------

// Redrawn every loop, but writeLine only pushes a line when it actually changes,
// so the prompt is effectively static until a scan flips it.
void drawSelectPrompt() {
  if (pendingSet < 0) {
    writeLine(0, "SCAN TO PICK SET", prevLine1);
    writeLine(1, "ANY A/B/C/D CARD", prevLine2);
  } else {
    char line1[LCD_COLS + 1];
    snprintf(line1, sizeof(line1), "SET %d SELECTED", pendingSet + 1);
    writeLine(0, line1, prevLine1);
    writeLine(1, "PRESS 1 TO START", prevLine2);
  }
}

void startSelect() {
  state = STATE_SELECT;
  pendingSet = -1;

  // Sync button 1's debouncer so a button already held at boot cannot confirm a
  // set the instant one is scanned.
  syncButton(0);

  lcd.clear();
  prevLine1[0] = '\0';
  prevLine2[0] = '\0';
  drawSelectPrompt();

  Serial.println(F("Select a set: scan any card from it, then press button 1."));
}

void updateSelect() {
  byte uid[UID_LENGTH];
  if (readUid(uid)) {
    int8_t s = matchSet(uid);
    if (s >= 0) {
      playTune(TUNE_SCAN, TUNE_SCAN_LENGTH);
      pendingSet = s;
      Serial.print(F("  set "));
      Serial.print(s + 1);
      Serial.println(F(" detected - press 1 to confirm, or scan another set"));
    } else {
      playTune(TUNE_WRONG, TUNE_WRONG_LENGTH);
      Serial.println(F("  unknown card - not part of any set"));
    }
  }

  drawSelectPrompt();

  // Button 1 confirms the highlighted set. Ignored until a set has been scanned.
  if (pendingSet >= 0 && buttonPressed(0)) {
    selectedSet = pendingSet;
    Serial.print(F("Set "));
    Serial.print(selectedSet + 1);
    Serial.println(F(" selected."));
    newGame();
  }
}

// ---------------------------------------------------------------------------
// Arduino entry points
// ---------------------------------------------------------------------------
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
void loop() {
  if (state == STATE_SELECT) { updateSelect(); return; }
  if (state != STATE_PLAYING) return;   // game is over; power-cycle to restart

  if (phase == PHASE_QUIZ) {
    byte uid[UID_LENGTH];
    if (readUid(uid)) {
      // Last scan wins. A card from another set matches nothing here and reads '?'.
      scannedCard = matchInSet(uid, selectedSet);
      playTune(TUNE_SCAN, TUNE_SCAN_LENGTH);
      Serial.print(F("    scanned card "));
      Serial.println(cardLetter(scannedCard));
    }
    renderQuiz();
  } else {
    // The pot is only read during a CODE phase. Reading it during the quiz would
    // put a live number on screen that means nothing yet.
    updatePotDigit();
    renderCode();
  }

  // Only the current level's button is live.
  if (buttonPressed(currentLevel)) {
    if (phase == PHASE_QUIZ) {
      submitAnswer();
    } else {
      submitDigit();
    }
  }
}

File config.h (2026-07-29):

/*
 * config.h - all tunable values for the BR Math Device.
 *
 * Everything you are likely to want to change lives in this file:
 * pin assignments, the answer key, the card UIDs, and the buzzer tunes.
 */

#ifndef CONFIG_H
#define CONFIG_H

#include <Arduino.h>

// ---------------------------------------------------------------------------
// Game shape
// ---------------------------------------------------------------------------
//
// Three levels holding nine questions between them. A level is not a single
// question: it is a run of questions (the QUIZ phase) followed by the digits of
// the code that level unlocks (the CODE phase).
//
//   Level | Questions | Code digits it locks
//     1   |     5     | 1, 2, 3
//     2   |     3     | 4
//     3   |     1     | 5
//
// LEVEL_QUESTIONS and LEVEL_CODE_DIGITS are the only source of truth for those
// counts. The sketch derives every offset into ANSWER_KEYS and the code by summing
// them, so there is no second table that has to be kept in agreement.

#define NUM_LEVELS       3
#define TOTAL_QUESTIONS  9   // must equal the sum of LEVEL_QUESTIONS
#define CODE_LENGTH      5   // must equal the sum of LEVEL_CODE_DIGITS

#define NUM_SETS    3   // three separate sets of paper questions, each with its own
                        // four cards and its own answer key. The player picks one at
                        // boot by scanning any card from it.
#define NUM_CARDS   4
#define UID_LENGTH  4   // Mifare Classic 1K UIDs are 4 bytes. If uid_dump reports
                        // a 7-byte UID, widen this to 7 and re-run it.

// constexpr, not plain const, so the static_asserts below can read them.
constexpr uint8_t LEVEL_QUESTIONS[NUM_LEVELS]   = { 5, 3, 1 };
constexpr uint8_t LEVEL_CODE_DIGITS[NUM_LEVELS] = { 3, 1, 1 };

// Change a level's question or digit count above and these catch the totals you
// forgot to change with it. Without them the mismatch is silent and shows up as
// the wrong answer key on the last question, or a code slot nobody can dial.
static_assert(LEVEL_QUESTIONS[0] + LEVEL_QUESTIONS[1] + LEVEL_QUESTIONS[2]
              == TOTAL_QUESTIONS, "TOTAL_QUESTIONS must equal the sum of LEVEL_QUESTIONS");
static_assert(LEVEL_CODE_DIGITS[0] + LEVEL_CODE_DIGITS[1] + LEVEL_CODE_DIGITS[2]
              == CODE_LENGTH, "CODE_LENGTH must equal the sum of LEVEL_CODE_DIGITS");

// Card identities. The numeric values index into CARD_UIDS below.
enum CardId : uint8_t {
  CARD_A       = 0,
  CARD_B       = 1,
  CARD_C       = 2,
  CARD_D       = 3,
  CARD_UNKNOWN = 4,   // a card was read, but its UID is not in the table
  CARD_NONE    = 5    // nothing scanned yet this question
};

// Which card answers each question, one row per set, laid out level by level. Level 1
// has five questions but there are only four cards, so one card must repeat in each
// row - kept far apart so it does not read as a pattern. Each row uses all four cards
// in its level-1 span and never repeats a card back-to-back.
//
// The three sets are different paper questions, so each has its own key. Edit a row to
// match whatever the paper for that set actually says.
// The outer dimension is left for the initializer to fill, so the static_assert
// below actually counts the rows written here. Pin it to [NUM_SETS] instead and the
// assert turns tautological - a forgotten row would just zero-fill (to all card A)
// and pass silently.
const CardId ANSWER_KEYS[][TOTAL_QUESTIONS] = {
  //  level 1 (Q1-Q5)                       level 2 (Q1-Q3)         level 3
  { CARD_B, CARD_D, CARD_A, CARD_C, CARD_D,  CARD_A, CARD_C, CARD_B,  CARD_D },  // set 1
  { CARD_C, CARD_A, CARD_D, CARD_B, CARD_A,  CARD_D, CARD_B, CARD_C,  CARD_A },  // set 2
  { CARD_D, CARD_B, CARD_C, CARD_A, CARD_B,  CARD_C, CARD_A, CARD_D,  CARD_B },  // set 3
};

static_assert(sizeof(ANSWER_KEYS) / sizeof(ANSWER_KEYS[0]) == NUM_SETS,
              "ANSWER_KEYS must have exactly NUM_SETS rows");
static_assert(sizeof(ANSWER_KEYS[0]) / sizeof(ANSWER_KEYS[0][0]) == TOTAL_QUESTIONS,
              "each ANSWER_KEYS row must have exactly TOTAL_QUESTIONS entries");

// ---------------------------------------------------------------------------
// Card UIDs
// ---------------------------------------------------------------------------
//
// Twelve cards: three sets of four (A, B, C, D). The values below were dumped
// from the physical cards and transcribed from rfid-uid.txt, in file order -
// lines 1-4 are set 1's A/B/C/D, lines 5-8 set 2, lines 9-12 set 3.
//
// ORDER MATTERS on two axes. The outer index picks the set (0=set 1, ...); the
// inner index must be A, B, C, D in that order, because ANSWER_KEYS above indexes
// into it. A wrong row scores that set's questions against the wrong card.
//
// To replace a card, flash tools/uid_dump/uid_dump.ino, tap it, and paste the new
// UID into the right [set][letter] slot. All-zero slots are treated as unconfigured.
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

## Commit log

2026-07-23 Rework 5 rounds into 3 levels (5/3/1 questions)
    Restructure the game from a flat 5-round quiz into 3 levels holding 9
    questions. Each level runs a QUIZ phase (answer its questions, one card
    each) then a CODE phase (dial its share of the 5-digit code): level 1
    locks digits 1-3, level 2 digit 4, level 3 digit 5.
    Wrong answers now cost a miss and keep the question live instead of
    advancing — every game ends solved, so the end screen reports MISSES
    rather than a score. Correct card blinks the level LED twice; a cleared
    level's LED goes solid. LEDs/buttons 4-5 stay wired but unused.
    Guard the level tables with static_asserts against TOTAL_QUESTIONS /
    CODE_LENGTH. Update TDD, README, and WIRIN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
    [circuit.fzz]
2026-07-29 Add 3 selectable question sets
    Player picks one of three question sets at boot by scanning any card
    from it and pressing button 1 to confirm; the existing 3-level flow
    then runs against that set alone. Only the selected set's cards score —
    a card from another set reads '?' and counts wrong.
    Grow the two per-set tables: CARD_UIDS becomes [3][4][4] (12 real UIDs
    from rfid-uid.txt, sequential blocks) and ANSWER_KEY becomes
    ANSWER_KEYS[3][9] with a distinct key per set. Refactor the RFID reader
    into readUid/matchInSet/matchSet so selection and play share one read.
    Leave the tables' outer dimension implicit so the row-count static_asserts
    actually bite instead of zero-filling silently.
    Update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
    [br-math-device.ino, config.h]
